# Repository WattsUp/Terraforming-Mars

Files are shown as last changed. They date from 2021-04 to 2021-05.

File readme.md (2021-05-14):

# Terraforming Mars Custom Box #
I made a custom box to hold the board game Terraforming Mars and 5 expansions: Venus Next, Colonies, Hellas & Elysium, Turmoil, and Prelude. I also 3D printed city tiles, greenery tiles, and every unique tile. Everything fits in a Pelican 1400 case (including the instruction manuals is right on the threshold of fitting easily).
Case exterior

## Components ##
Components laid out
- [Pelican 1400 case](https://www.pelican.com/us/en/product/cases/protector/1400)
- `Case_TreeTray` in forest green
  - [32 Greenery tiles by Srifraf](https://www.thingiverse.com/thing:3153866)
  - 9 Ocean tiles
  - 7 Unique tiles
- `Case_CityTray` in grey
  - 16 Generic city tiles
  - 30 Unique tiles
  - [1st player marker by hakosalio](https://www.thingiverse.com/thing:3788007) and original circle markers
  - Colonies with overlay `Games_ColoniesV2` remixed from [flocor](https://www.thingiverse.com/thing:3302615) and Trade Fleets Tile
  - Small game boards (Venus Next, Turmoil) and small rulebooks (Venus Next, Turmoil, Colonies, and Prelude)
  - Player mats with [overlay by aimfeld](https://www.thingiverse.com/thing:2988374)
  - [Resource cube box by lapiter](https://www.thingiverse.com/thing:4272405) with ~30 [action markers by lapiter](https://www.thingiverse.com/thing:4270469)
- `Case_CardTray` in black
  - Player cubes and Turmoil delegates
  - Global parameter tracking cubes and colony tracking cubes
  - Colony freighters (original and custom by [Pkrdays](https://www.thingiverse.com/thing:4708111), [ambug666](https://www.thingiverse.com/thing:3342891), and [JimmerJammer](https://www.thingiverse.com/thing:3285321))
  - [Turmoil committee by hd42](https://www.thingiverse.com/thing:4056897) and policy tiles
  - Terraformer milestone replacement tile (from Turmoil)
  - Hoverlord milestone and Venuphile award tiles (from Venus Next)
  - All project cards, Turmoil event, Prelude projects, corporations, and the other reference cards
  - Tharsis and Hellas & Elysium maps
  - Base rulebook and Hellas & Elysium rules
- Many space themed stickers

## Construction Notes ##
- My printer was too small for a single print so I split each piece in two and used CA glue to recombine.
- The embossed text on the card tray is hard to read in black plastic, you could paint it
- Printing all custom freighters technically fits in the specified box but takes a while to Tetris it out. You could print fewer freighters or use the miscellaneous cubby.
- My Pelican 1400's bottom and top were warped from the injection molded plastic shrinking. Since its minimum dimensions still matched the provided CAD, I assume it is on all units. I printed two `Case_TreeTrayShim` and placed them on either side of the case's hump.
- To mitigate short tiles from shifting when the case is inverted, I cut the foam that came with the case to fit the tiles.
- Hand painting the printed tiles requires patience and/or friends. You could print with multiple filament colors as instructed in Srifraf's design.
- The original tiles do not have a reserved cubby. No need to include them unless you expect to have a very intensive ground game in excess of 16 generic cities and/or 32 greenery tiles. There is likely room in the city tray albeit unsecured.

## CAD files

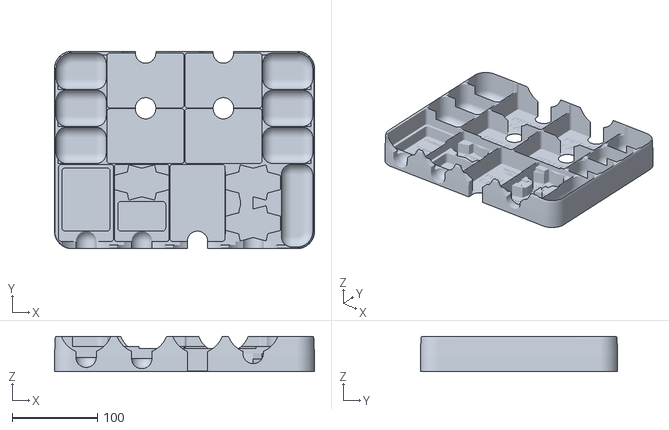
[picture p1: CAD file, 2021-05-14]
STL/Case_CardTray.stl
305.8 x 232.1 x 41.5

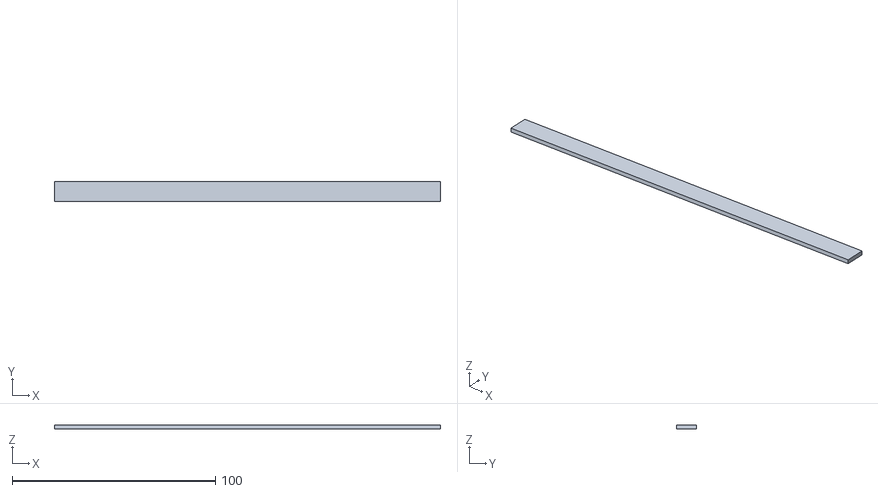
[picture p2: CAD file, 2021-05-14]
STL/Case_TreeTrayShim.stl
190.0 x 10.0 x 2.00

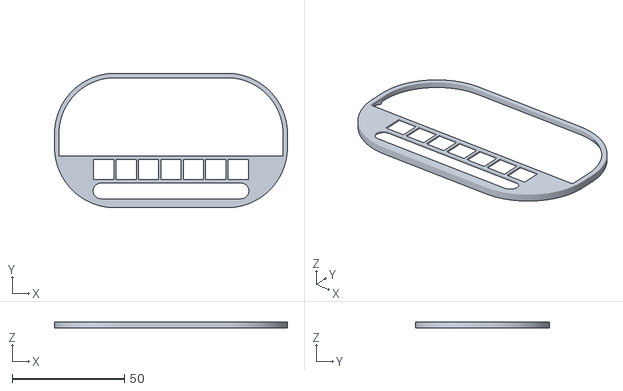
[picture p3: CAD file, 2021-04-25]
STL/Game_ColoniesV2.stl
104.0 x 60.0 x 2.90

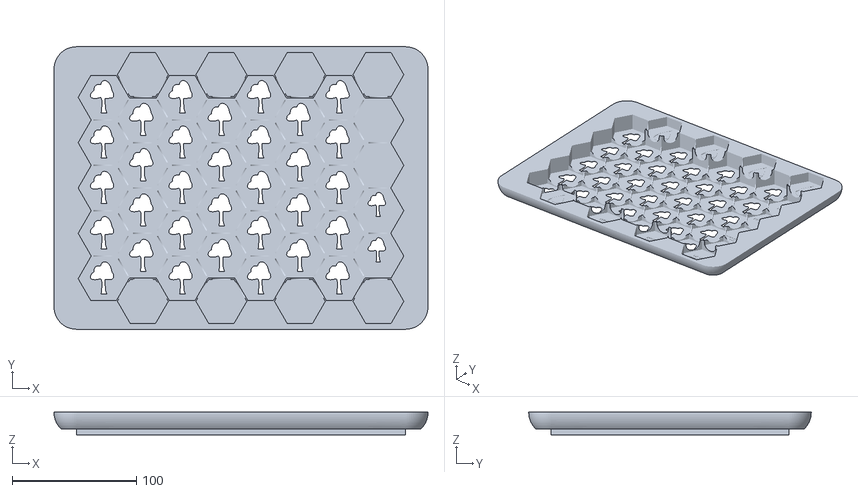
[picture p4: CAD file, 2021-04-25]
STL/Case_TreeTray.stl
301.2 x 227.5 x 18.5

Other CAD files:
COTS/1400-bot.ipt
COTS/1400-top.ipt
COTS/1st_player.ipt
COTS/1st_player_mirrored.ipt
COTS/2020Nuclear.ipt
COTS/TMOceanTile1Final2019.ipt
COTS/TurmoilParliamentFaction.ipt
COTS/TurmoilParliamentPlatformV3.ipt
COTS/terraforming_mars_resource_box_body.ipt
Case_TreeTrayShim.ipt
Game_CardDeck.ipt
Game_CardDeck0.25.ipt
Game_CircleMarkers.ipt
Game_Colonies.ipt
Game_ColoniesV2.ipt
Game_ColonyPort.ipt
Game_Corporations.ipt
Game_ExpansionMaps.ipt
Game_HelperCards.ipt
Game_Map.ipt
Game_PlayerCards.ipt
Game_PlayerCubes.ipt
Game_Prelude.ipt
Game_TrackingCube.ipt
Game_TurmoilEvents.ipt
Game_TurmoilPolicy.ipt
Game_TurmoilTerraformerReplacement.ipt
Game_VenusAwards.ipt

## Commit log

2021-04-25 Adjusted ocean tile finger access
    [Case_TreeTray.stl]
2021-04-25 Adjusted colony overlay geometry
    [Game_ColoniesV2.ipt, Game_ColoniesV2.stl]
2021-05-14 Adjusted city tray and redesigned card tray
    [1400-top.ipt, Case_CardTray.stl, Case_TreeTrayShim.ipt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]
